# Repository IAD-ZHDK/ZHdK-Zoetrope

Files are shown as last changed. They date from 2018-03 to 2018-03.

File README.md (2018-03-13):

# ZHdK-Zoetrope

PCB layout for Zoetrope controller using IR sensor. The rotating plate acts as an encoder wheel, allowing for easy change of frame rate.

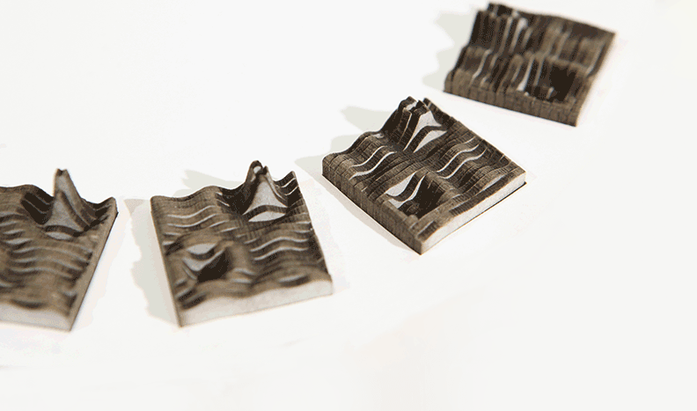
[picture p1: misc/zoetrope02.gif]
Zoetrope


## Parts

### Motors

- Micro Geared motor `gm12f-n20va` ([play-zone](https://www.play-zone.ch/en/elektromotor-mit-getriebe-gm12f-n20va.html))
- IR sensor `gm12f-n20va` ([Datasheet](https://www.mouser.ch/ds/2/427/tcrt1000-280041.pdf),[Mouser](https://www.mouser.ch/ProductDetail/Vishay-Semiconductors/TCRT1000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))
-  Geared motor large (requires modification of board) `L149-12-43` ([datasheet](https://www.distrelec.ch/Web/Downloads/80/06/05448006.pdf))
-  High Power LED `CXA1304-0000-000C0HC457F` ([datasheet](https://www.mouser.ch/ds/2/90/20130621CLDDS73CXA1304Rev0-267980.pdf),[mouser](https://www.mouser.ch/ProductDetail/941-CXA13040C0HC457F))

## Notes
-  ([Assembly guide](https://github.com/IAD-ZHDK/ZHdK-Zoetrope/blob/master/misc/zootrope3Dguide.pdf))

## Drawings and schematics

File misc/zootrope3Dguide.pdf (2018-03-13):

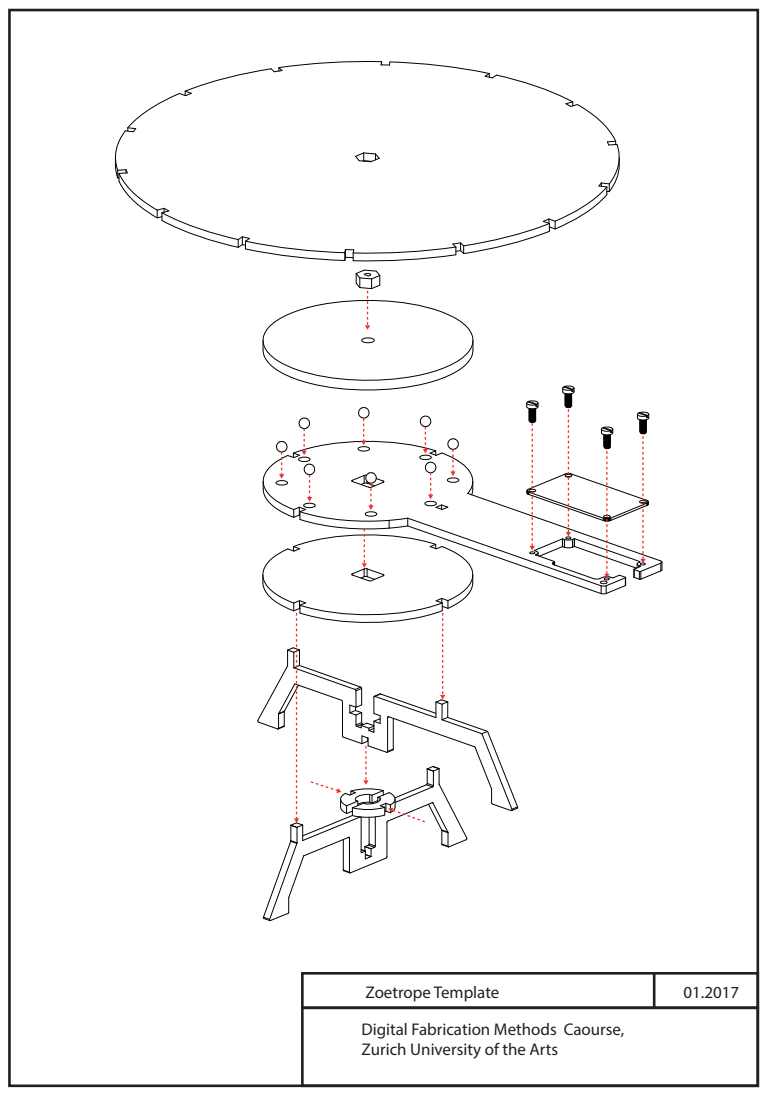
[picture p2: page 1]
Zoetrope Template

Digital Fabrication Methods Caourse,
Zurich University of the Arts

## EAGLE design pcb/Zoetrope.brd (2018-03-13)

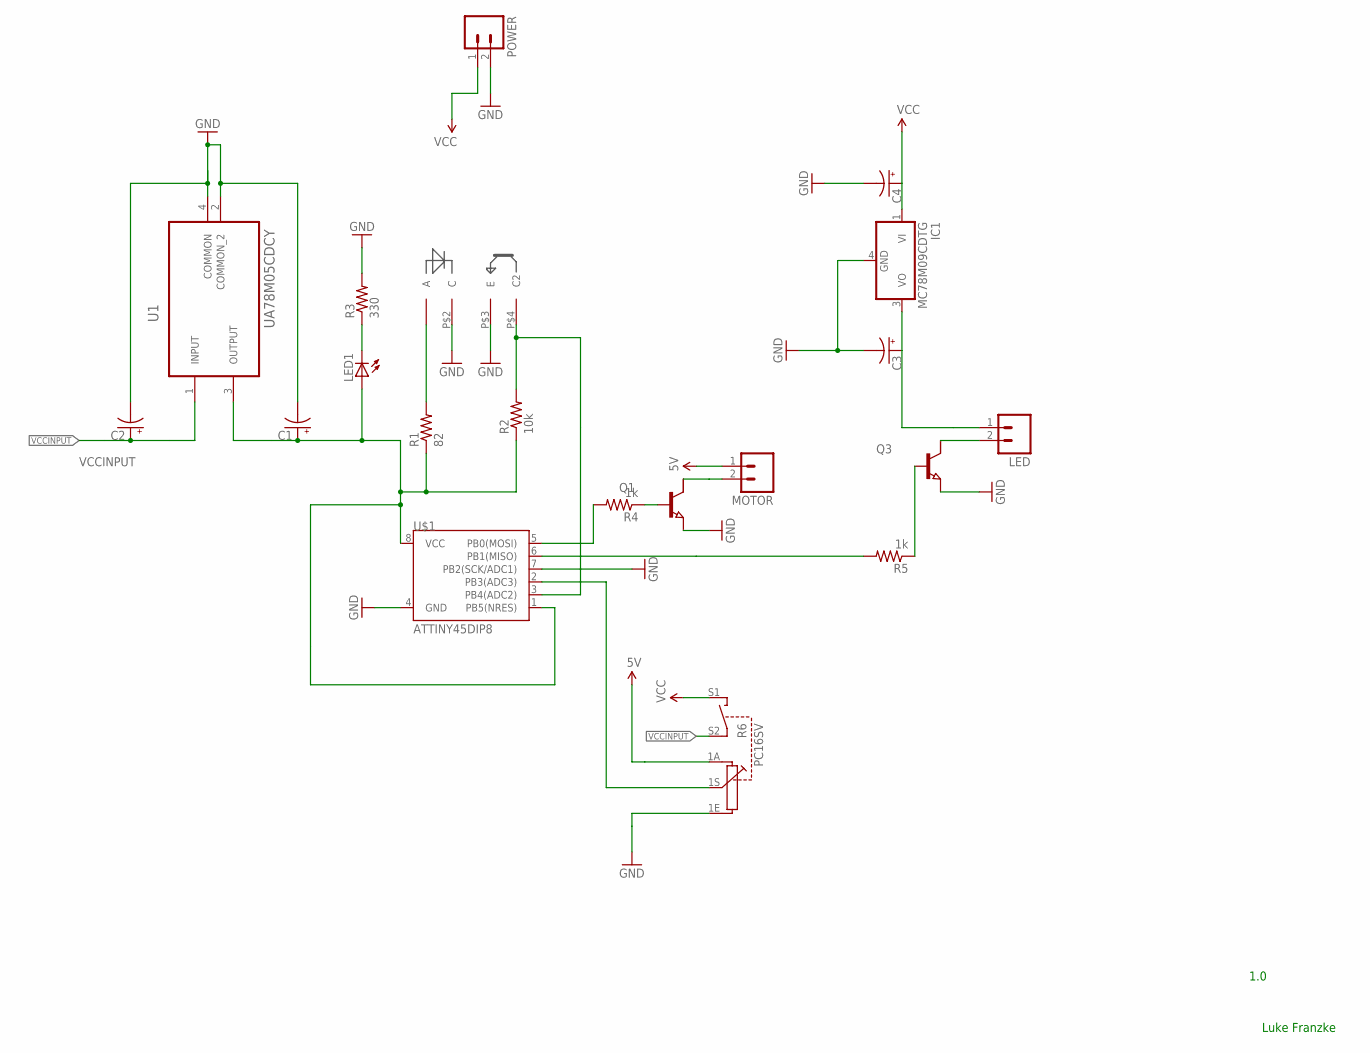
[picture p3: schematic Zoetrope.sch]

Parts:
C1, C2, C3, C4: CAP_POL1206; EIA3216
IC1: MC78M09CDTG; DPACK_3
LED: M02; 02P
LED1: LED1206; LED-1206
MOTOR: M02; 02P
POWER: M02; 02P
Q1, Q3: NPN-TRANSISTIOR-2COLSOT89; SOT89
R1: 82; 1206
R2: 10k; 1206
R3: 330; 1206
R4, R5: 1k; 1206
R6: PC16SV
U1: UA78M05CDCY; SOT230P700X180-4N
U$1: ATTINY45DIP8; DIP08
U$2: TCRT1000

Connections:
5V: C1.A (+), LED1.A, MOTOR.1, R1.1, R2.1, R6.1A, U1.3 (OUTPUT), U$1.1 (PB5(NRES)), U$1.8 (VCC)
GND: C1.C (-), C2.C (-), C3.C (-), C4.C (-), IC1.4 (GND), POWER.2, Q1.3 (E), Q3.3 (E), R3.2, R6.1E, U1.2 (COMMON_2), U1.4 (COMMON), U$1.4 (GND), U$1.7 (PB2(SCK/ADC1)), U$2.P$2 (C), U$2.P$3 (E)
unnamed: R5.2, U$1.6 (PB1(MISO))
unnamed: LED1.C, R3.1
unnamed: LED.2, Q3.2 (C)
unnamed: R1.2, U$2.P$1 (A)
unnamed: R2.2, U$1.3 (PB4(ADC2)), U$2.P$4 (C2)
unnamed: R6.1S, U$1.2 (PB3(ADC3))
unnamed: Q3.1 (B), R5.1
unnamed: Q1.1 (B), R4.1
unnamed: R4.2, U$1.5 (PB0(MOSI))
unnamed: MOTOR.2, Q1.2 (C)
unnamed: C3.A (+), IC1.3 (VO), LED.1
VCC: C4.A (+), IC1.1 (VI), POWER.1, R6.S1
VCCINPUT: C2.A (+), R6.S2, U1.1 (INPUT)

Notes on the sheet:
Luke Franzke
1.0

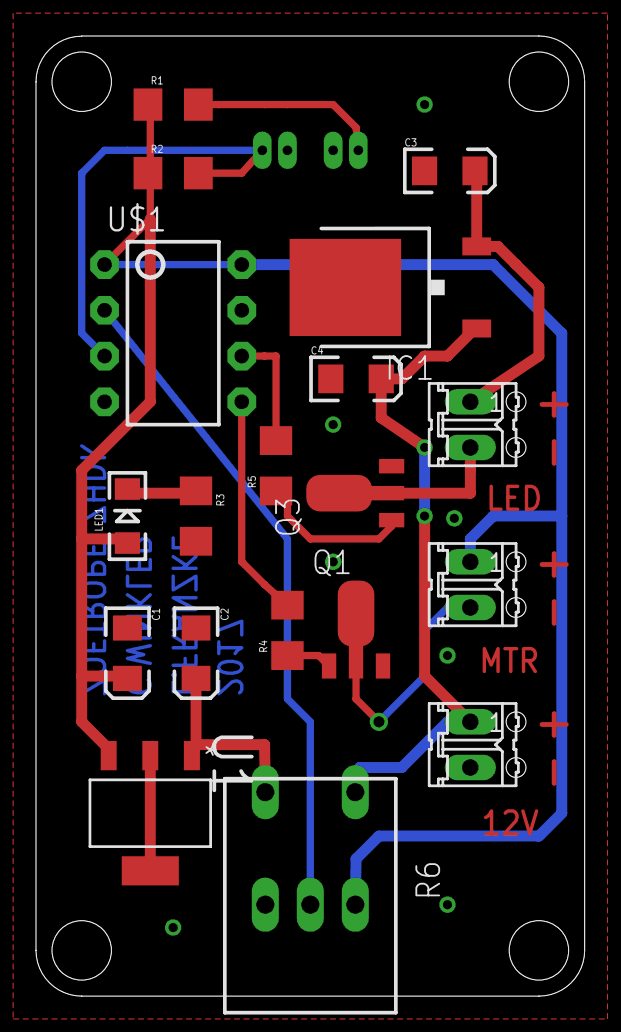
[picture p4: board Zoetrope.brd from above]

Board: 2 copper layers, 30.5 x 53.3 mm, 24 parts (1 on the bottom side), 15 nets.

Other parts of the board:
U$4, U$5, U$6, U$7: STAND-OFF

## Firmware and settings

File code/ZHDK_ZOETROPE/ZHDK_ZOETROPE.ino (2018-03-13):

/*
 * Arduino ATTINY85 code for the IAD ZHdK Zoetrope 
 * Author: Luke Franzke 
 * luke.franzke@zhdk.ch 
 * 2017
 * This example code is in the public domain.
 */

const int analogInPin = A2;  // Distance sensor
const int analogInPin2 = A3;  // Poti for motor
const int digOutPin = 1; // LED
const int pwmOutPin = 0; //Motor
const int ledTrigger = 280;
const int maxLedTime = 25; // maximum duration of led flash

int sensorValue = 0;   // value read from the distance sensor
int motorSpeed=0;
int lightCount = 0;
boolean trigerTag = false;

int flashTime = 1; //duration of flash

void setup() {
  pinMode(digOutPin, OUTPUT);
  pinMode(pwmOutPin, OUTPUT);
  pinMode(analogInPin, INPUT);
  pinMode(analogInPin2, INPUT);
}

void loop() {
  lightCount++;
  sensorValue = analogRead(analogInPin);

  if (sensorValue >= ledTrigger && trigerTag == true) {
    lightCount = 0;
    trigerTag = false;
  }
  // make sure the led can't be trigered again imediatly 
  if (sensorValue < ledTrigger && lightCount >= flashTime*2) {
    trigerTag = true;
  }
  if (lightCount >= flashTime) {
    digitalWrite(digOutPin, LOW);
  } else { 

    digitalWrite(digOutPin, HIGH);

  }
  motorSpeed = map(analogRead(analogInPin2), 0, 1024, 0, 255);
   // Flash duration is maped to corelate to motor speed.
  flashTime = floor(map(motorSpeed, 0, 255, maxLedTime, 1)); 
  
  if (motorSpeed>=30) {
  analogWrite(pwmOutPin, motorSpeed);
  }
  // reset lightcount
  if (lightCount >= 1000) {
    lightCount = flashTime * 2;
  }
}

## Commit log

2018-03-13 PCB and code added
    [Zoetrope.brd, Zoetrope.sch]
2018-03-13 added misc material

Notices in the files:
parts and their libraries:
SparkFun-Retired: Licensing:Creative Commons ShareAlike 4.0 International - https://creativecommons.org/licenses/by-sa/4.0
